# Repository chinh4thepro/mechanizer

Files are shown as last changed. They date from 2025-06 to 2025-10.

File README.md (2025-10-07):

tag

## What and Why?

This is an ortholinear, split keyboard with wireless functionality and a display with a theme based on the song Mesmerizer by 32ki. I designed this keyboard to improve on issues I had with my previous ortholinear keyboard design, the blahajergo.

## Images

### Overall
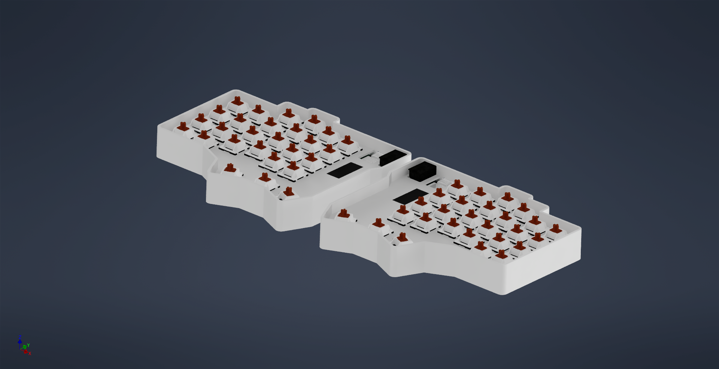
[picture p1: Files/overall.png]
Overall


### Schematic
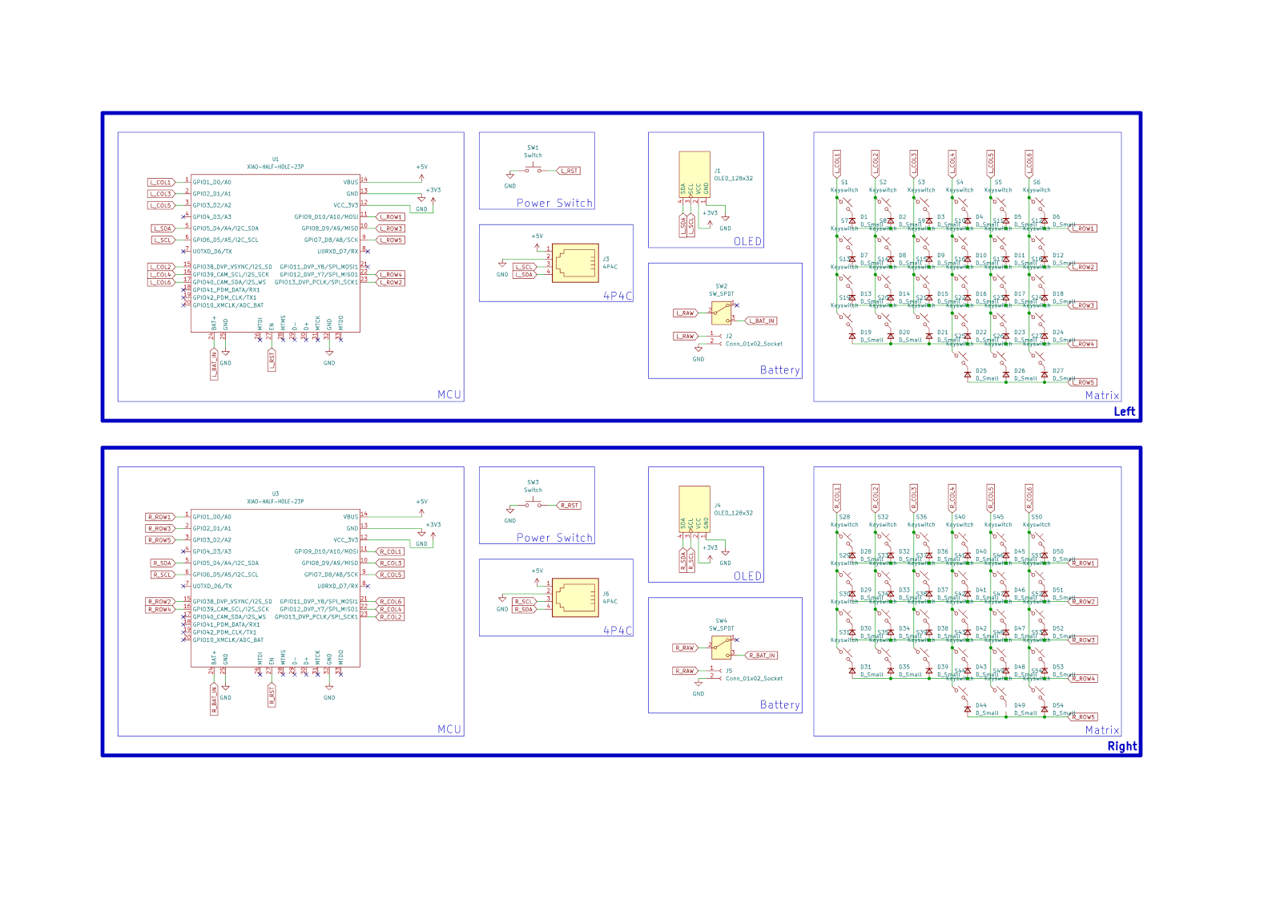
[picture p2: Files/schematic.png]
Schematic


### PCB
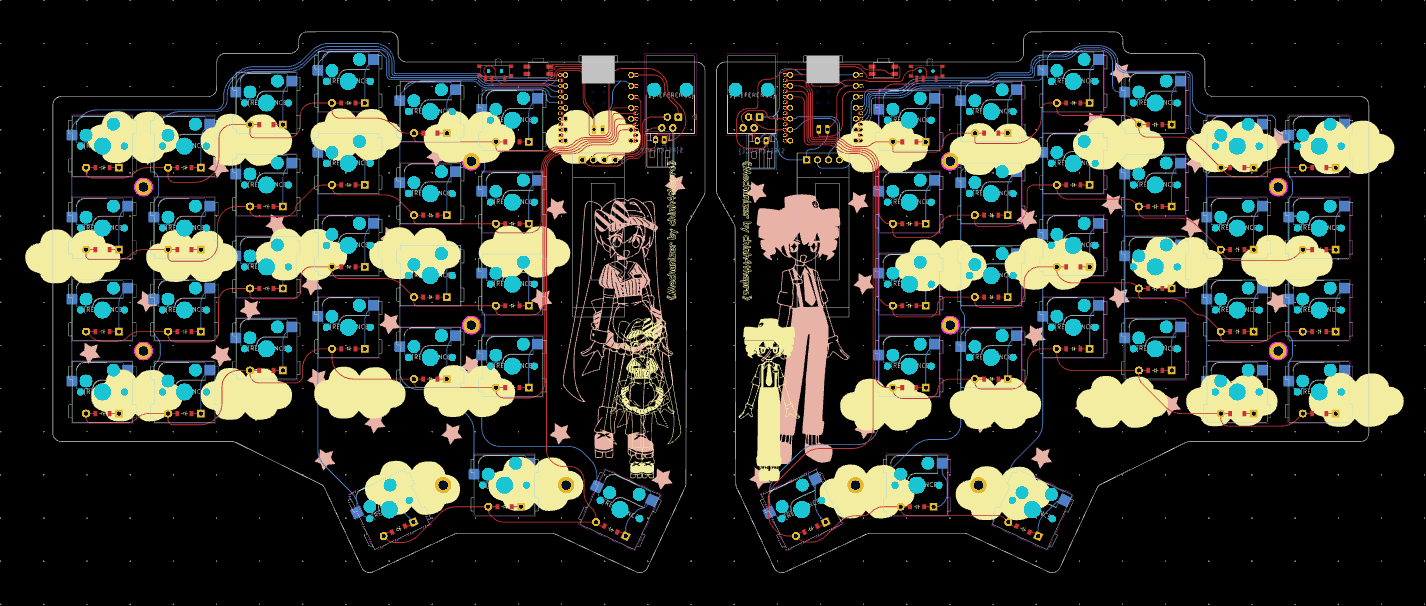
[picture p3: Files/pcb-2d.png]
PCB-2d

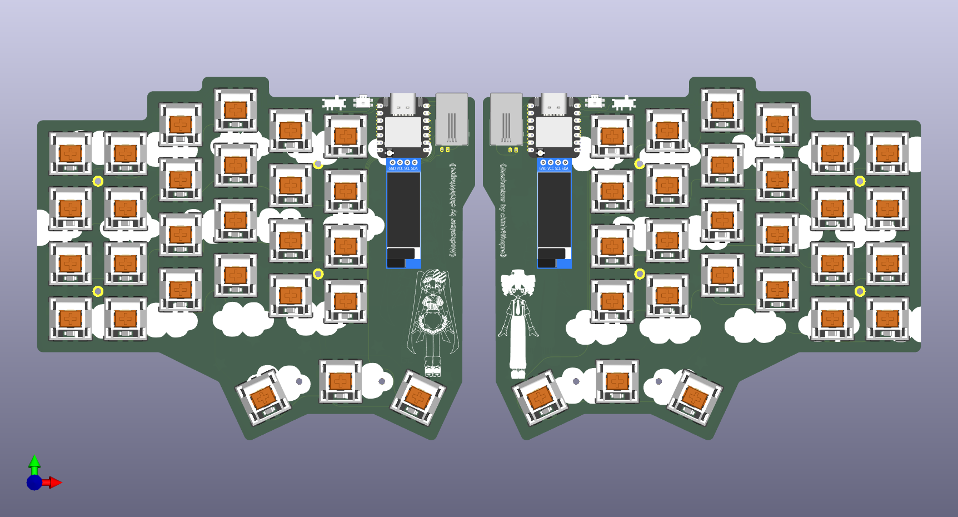
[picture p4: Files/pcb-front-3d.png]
PCB-3d-f

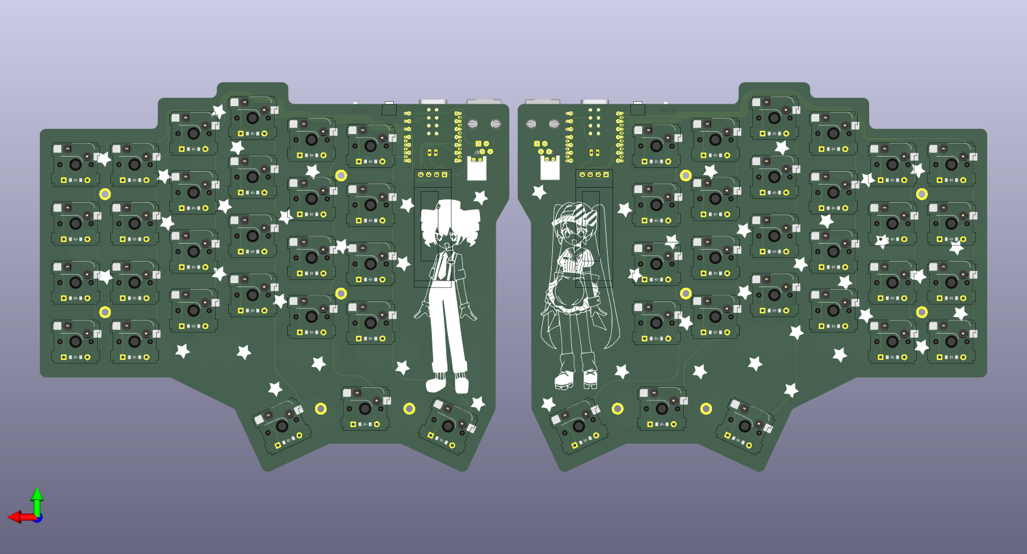
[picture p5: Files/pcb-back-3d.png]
PCB-3d-b


## BOM

| Name | Qty | Price | Vendor | Link |
|---|---|---|---|---|
| THT 1N4148 Diodes | 54 | $0.00 | HackClub | N/A |
| KBDiy Toy | 54 | $24.45 | AliExpress | https://www.aliexpress.us/item/3256807300360436.html |
| JWK Linear Switches | 54 | $14.4 | typeractive | https://typeractive.xyz/products/jwk-jwick-linear-switches?variant=45434593968359 |
| Kalih MX hotswap sockets | 54 | $13.45 | AliExpress | https://www.aliexpress.us/item/3256808768257055.html |
| 4P4C jack | 2 | $1.87 | AliExpress | https://www.aliexpress.us/item/3256807699240291.html |
| JST connector | 2 | $0.73 | AliExpress | https://www.aliexpress.us/item/3256808844534562.html |
| 0.91" Oled display | 2 | $1.96 | AliExpress | https://www.aliexpress.us/item/3256805114690528.html |
| 3.7v Lithium battery | 2 | $8.00 | typeractive | https://typeractive.xyz/products/lithium-battery-110mah?variant=43294731665639 |
| JST connector | 2 | $1.00 | typeractive | https://typeractive.xyz/products/battery-jack?variant=45597492707559 |
| SMD side button | 2 | $1.50 | typeractive | https://typeractive.xyz/products/reset-button |
| SPDT Switch | 2 | $1.50 | typeractive | https://typeractive.xyz/products/power-switch?variant=45597854171367 |
| M2 screws | 24 | $2.44 | AliExpress | https://www.aliexpress.us/item/2255799870438450.html |
| M2 standoffs | 12 | $5.40 | AliExpress | https://www.aliexpress.us/item/3256806016664762.html |
| Seeed XIAO ESP32-S3 Plus (already own) | 2 | $13.80 | seeedstudio | https://www.seeedstudio.com/Seeed-Studio-XIAO-ESP32S3-Plus-p-6361.html |
| PCB | 1 (5) | $36.92 | jlcpcb | See jlcpcb pic in Files |

| Total                                                                                                                                             |
|---------------------------------------------------------------------------------------------------------------------------------------------------|
| AliExpress: $52.83 subtotal + $4.24 shipping + $3.33 fees = $58.61 total                                                                          |
| typeractive: $26.40 subtotal + $0.00 shipping + $0.00 fees = $26.40 total                                                                         |
| seeedstudio: $0.00 subtotal + $0.00 shipping + $0.00 fees = $0.00 total                                                                           |
| jlcpcb: $21.40 subtotal + $15.52 shipping + $0.00 fees = $36.92 total                                                                             |
| Total: $121.93                                                                                                                                     |

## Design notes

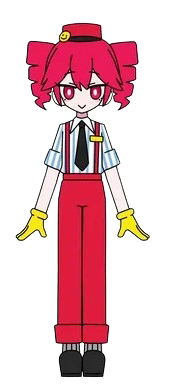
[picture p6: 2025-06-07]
Files/teto-1.png

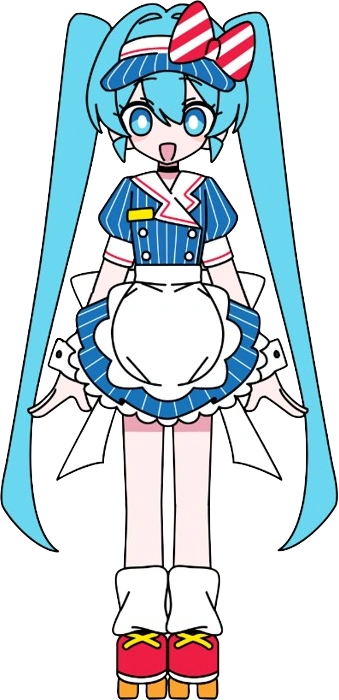
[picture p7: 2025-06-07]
Files/miku-1.png

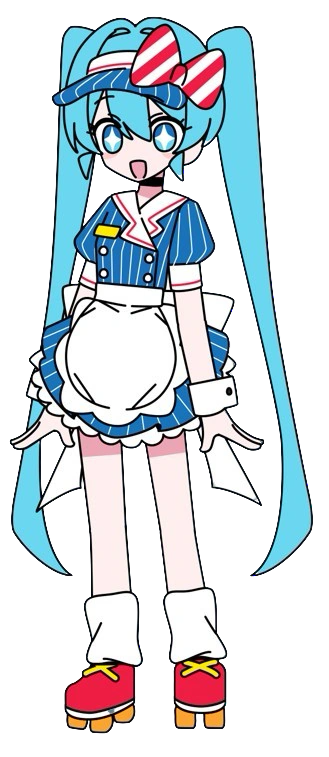
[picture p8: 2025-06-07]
Files/miku-2.png

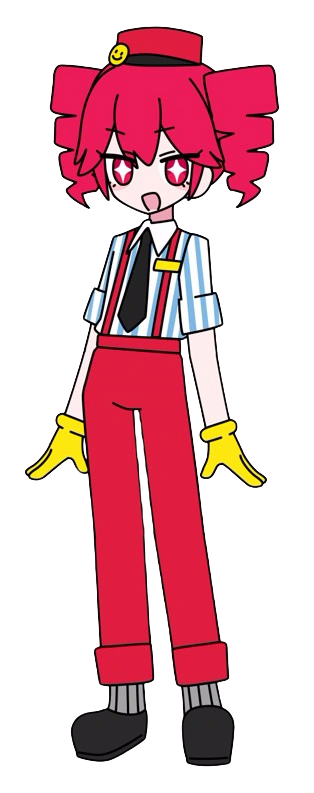
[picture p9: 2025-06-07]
Files/teto-2.png

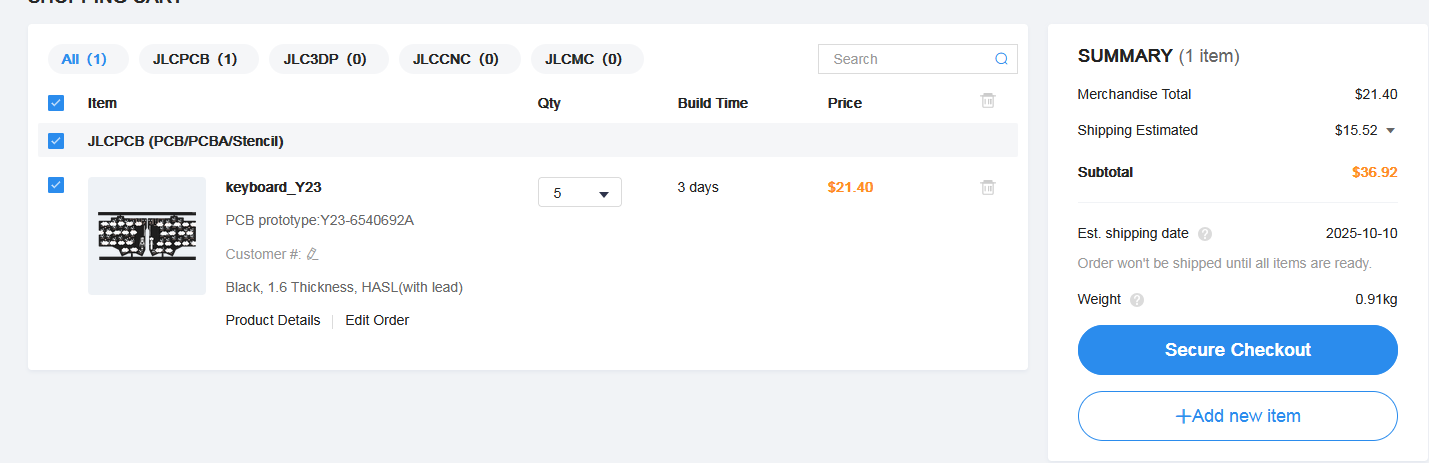
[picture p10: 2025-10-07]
Files/jlcpcb.png

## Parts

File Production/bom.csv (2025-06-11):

Designator | Footprint | Quantity | Value | LCSC Part #
D1, D10, D11, D12, D13, D14, D15, D16, D17, D18, D19, D2, D20, D21, D22, D23, D24, D25, D26, D27, D28, D29, D3, D30, D31, D32, D33, D34, D35, D36, D37, D38, D39, D4, D40, D41, D42, D43, D44, D45, D46, D47, D48, D49, D5, D50, D51, D52, D53, D54, D6, D7, D8, D9 | ComboDiode | 54 | D_Small
H1, H10, H11, H12, H2, H3, H4, H5, H6, H7, H8, H9 | mounting_hole_plated | 12
J1, J4 | OLED_128x32 | 2 | OLED_128x32
J2, J5 | JST_PH_S2B-PH-K_1x02_P2.00mm_Horizontal | 2 | Conn_01x02_Socket
J3, J6 | RJ9_Evercom_5301-440xxx_Horizontal | 2 | 4P4C
S1, S10, S11, S12, S13, S14, S15, S16, S17, S18, S19, S2, S20, S21, S22, S23, S24, S25, S26, S27, S28, S29, S3, S30, S31, S32, S33, S34, S35, S36, S37, S38, S39, S4, S40, S41, S42, S43, S44, S45, S46, S47, S48, S49, S5, S50, S51, S52, S53, S54, S6, S7, S8, S9 | Hotswap_MX | 54 | Keyswitch
SW1, SW3 | reset_switch_smd_side | 2 | Switch
SW2, SW4 | power_switch_smd_side | 2 | SW_SPDT
U1, U3 | Xiao_ESP32S3_Plus.kicad_sym | 2 | XIAO-HALF-HOLE-23P

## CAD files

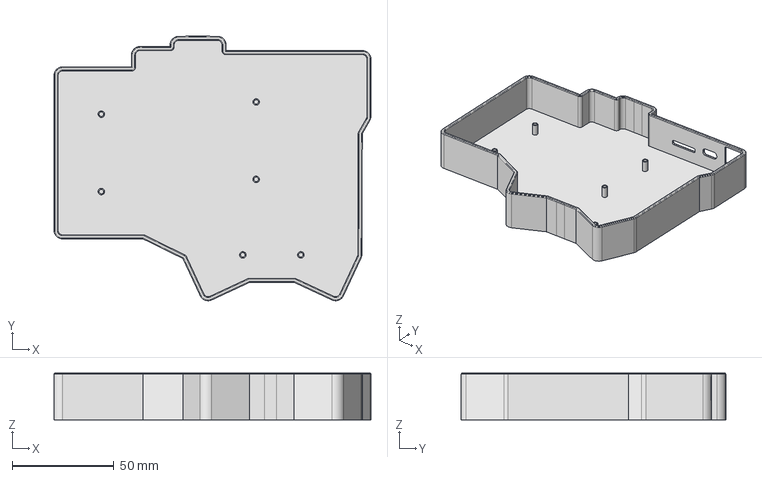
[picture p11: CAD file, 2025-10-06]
CAD/Exports/Left_Shell.step
155.6 x 129.9 x 23.0 mm

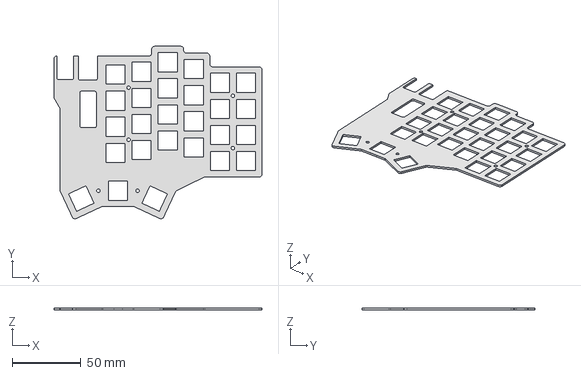
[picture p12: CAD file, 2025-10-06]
CAD/Exports/Right_Plate.step
151.4 x 125.7 x 1.50 mm

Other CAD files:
CAD/Exports/Right_Shell.step
CAD/Exports/Left_Plate.step
CAD/Exports/Left_Plate.3mf
CAD/Exports/Left_Shell.3mf
CAD/Exports/Right_Plate.3mf
CAD/Exports/Right_Shell.3mf

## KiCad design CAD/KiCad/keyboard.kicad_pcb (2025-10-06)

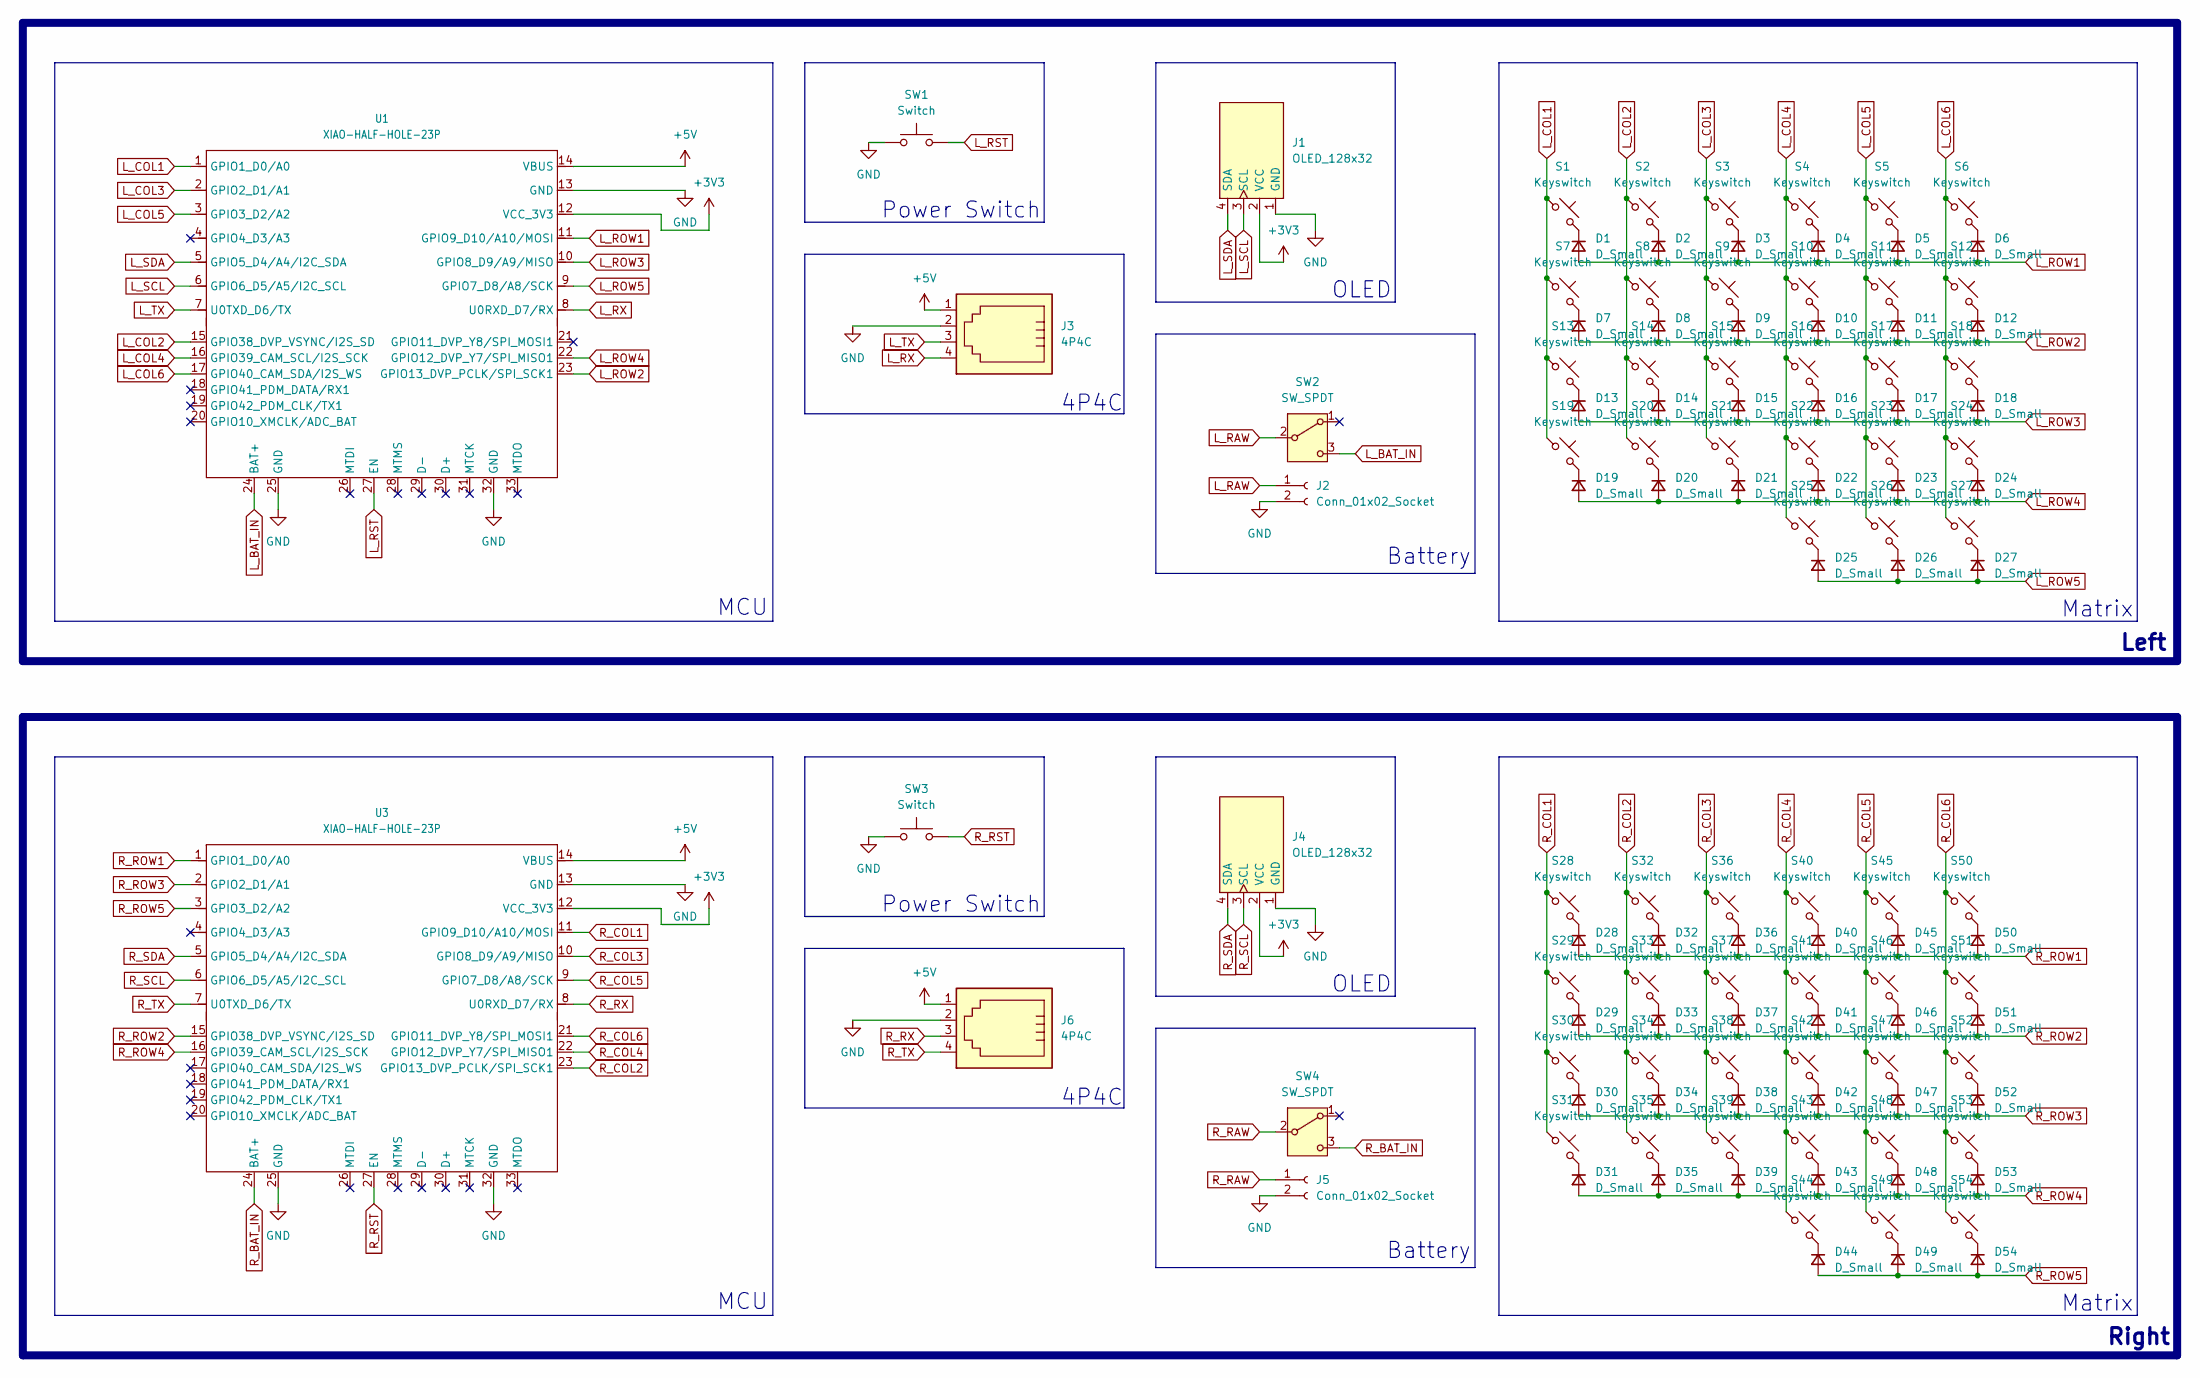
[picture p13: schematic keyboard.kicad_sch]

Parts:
D1, D2, D3, D4, D5, D6, D7, D8, D9, D10, D11, D12, D13, D14, D15, D16, D17, D18, D19, D20, D21, D22, D23, D24, D25, D26, D27, D28, D29, D30, D31, D32, D33, D34, D35, D36, D37, D38, D39, D40, D41, D42, D43, D44, D45, D46, D47, D48, D49, D50, D51, D52, D53, D54: D_Small; ComboDiode
J1, J4: OLED_128x32
J2, J5: Conn_01x02_Socket; JST_PH_S2B-PH-K_1x02_P2.00mm_Horizontal
J3, J6: 4P4C; RJ9_Evercom_5301-440xxx_Horizontal
S1, S2, S3, S4, S5, S6, S7, S8, S9, S10, S11, S12, S13, S14, S15, S16, S17, S18, S19, S20, S21, S22, S23, S24, S25, S26, S27, S28, S29, S30, S31, S32, S33, S34, S35, S36, S37, S38, S39, S40, S41, S42, S43, S44, S45, S46, S47, S48, S49, S50, S51, S52, S53, S54: Keyswitch; Hotswap_MX
SW1, SW3: Switch; reset_switch_smd_side
SW2, SW4: SW_SPDT; power_switch_smd_side
U1, U3: XIAO-HALF-HOLE-23P; Xiao_ESP32S3_Plus.kicad_sym

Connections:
+3V3: J1.2 (VCC), J4.2 (VCC), U1.12 (VCC_3V3), U3.12 (VCC_3V3)
+5V: J3.1, J6.1, U1.14 (VBUS), U3.14 (VBUS)
GND: J1.1 (GND), J2.2, J3.2, J4.1 (GND), J5.2, J6.2, SW1.1, SW3.1, U1.13 (GND), U1.25 (GND), U1.32 (GND), U3.13 (GND), U3.25 (GND), U3.32 (GND)
L_BAT_IN: SW2.3 (C), U1.24 (BAT+)
L_COL1: S1.1, S7.1, S13.1, S19.1, U1.1 (GPIO1_D0/A0)
L_COL2: S2.1, S8.1, S14.1, S20.1, U1.15 (GPIO38_DVP_VSYNC/I2S_SD)
L_COL3: S3.1, S9.1, S15.1, S21.1, U1.2 (GPIO2_D1/A1)
L_COL4: S4.1, S10.1, S16.1, S22.1, S25.1, U1.16 (GPIO39_CAM_SCL/I2S_SCK)
L_COL5: S5.1, S11.1, S17.1, S23.1, S26.1, U1.3 (GPIO3_D2/A2)
L_COL6: S6.1, S12.1, S18.1, S24.1, S27.1, U1.17 (GPIO40_CAM_SDA/I2S_WS)
L_RAW: J2.1, SW2.2 (B)
L_ROW1: D1.2 (A), D2.2 (A), D3.2 (A), D4.2 (A), D5.2 (A), D6.2 (A), U1.11 (GPIO9_D10/A10/MOSI)
L_ROW2: D7.2 (A), D8.2 (A), D9.2 (A), D10.2 (A), D11.2 (A), D12.2 (A), U1.23 (GPIO13_DVP_PCLK/SPI_SCK1)
L_ROW3: D13.2 (A), D14.2 (A), D15.2 (A), D16.2 (A), D17.2 (A), D18.2 (A), U1.10 (GPIO8_D9/A9/MISO)
L_ROW4: D19.2 (A), D20.2 (A), D21.2 (A), D22.2 (A), D23.2 (A), D24.2 (A), U1.22 (GPIO12_DVP_Y7/SPI_MISO1)
L_ROW5: D25.2 (A), D26.2 (A), D27.2 (A), U1.9 (GPIO7_D8/A8/SCK)
L_RST: SW1.2, U1.27 (EN)
L_RX: J3.4, U1.8 (U0RXD_D7/RX)
L_SCL: J1.3 (SCL), U1.6 (GPIO6_D5/A5/I2C_SCL)
L_SDA: J1.4 (SDA), U1.5 (GPIO5_D4/A4/I2C_SDA)
L_TX: J3.3, U1.7 (U0TXD_D6/TX)
unnamed: D1.1 (K), S1.2
unnamed: D2.1 (K), S2.2
unnamed: D3.1 (K), S3.2
unnamed: D4.1 (K), S4.2
unnamed: D5.1 (K), S5.2
unnamed: D6.1 (K), S6.2
unnamed: D7.1 (K), S7.2
unnamed: D8.1 (K), S8.2
unnamed: D9.1 (K), S9.2
unnamed: D10.1 (K), S10.2
unnamed: D11.1 (K), S11.2
unnamed: D12.1 (K), S12.2
unnamed: D13.1 (K), S13.2
unnamed: D14.1 (K), S14.2
unnamed: D15.1 (K), S15.2
unnamed: D16.1 (K), S16.2
unnamed: D17.1 (K), S17.2
unnamed: D18.1 (K), S18.2
unnamed: D19.1 (K), S19.2
unnamed: D20.1 (K), S20.2
unnamed: D21.1 (K), S21.2
unnamed: D22.1 (K), S22.2
unnamed: D23.1 (K), S23.2
unnamed: D24.1 (K), S24.2
unnamed: D25.1 (K), S25.2
unnamed: D26.1 (K), S26.2
unnamed: D27.1 (K), S27.2
unnamed: D28.1 (K), S28.2
unnamed: D29.1 (K), S29.2
unnamed: D30.1 (K), S30.2
unnamed: D31.1 (K), S31.2
unnamed: D32.1 (K), S32.2
unnamed: D33.1 (K), S33.2
unnamed: D34.1 (K), S34.2
unnamed: D35.1 (K), S35.2
unnamed: D36.1 (K), S36.2
unnamed: D37.1 (K), S37.2
unnamed: D38.1 (K), S38.2
unnamed: D39.1 (K), S39.2
unnamed: D40.1 (K), S40.2
unnamed: D41.1 (K), S41.2
unnamed: D42.1 (K), S42.2
unnamed: D43.1 (K), S43.2
unnamed: D44.1 (K), S44.2
unnamed: D45.1 (K), S45.2
unnamed: D46.1 (K), S46.2
unnamed: D47.1 (K), S47.2
unnamed: D48.1 (K), S48.2
unnamed: D49.1 (K), S49.2
unnamed: D50.1 (K), S50.2
unnamed: D51.1 (K), S51.2
unnamed: D52.1 (K), S52.2
unnamed: D53.1 (K), S53.2
unnamed: D54.1 (K), S54.2
R_BAT_IN: SW4.3 (C), U3.24 (BAT+)
R_COL1: S28.1, S29.1, S30.1, S31.1, U3.11 (GPIO9_D10/A10/MOSI)
R_COL2: S32.1, S33.1, S34.1, S35.1, U3.23 (GPIO13_DVP_PCLK/SPI_SCK1)
R_COL3: S36.1, S37.1, S38.1, S39.1, U3.10 (GPIO8_D9/A9/MISO)
R_COL4: S40.1, S41.1, S42.1, S43.1, S44.1, U3.22 (GPIO12_DVP_Y7/SPI_MISO1)
R_COL5: S45.1, S46.1, S47.1, S48.1, S49.1, U3.9 (GPIO7_D8/A8/SCK)
R_COL6: S50.1, S51.1, S52.1, S53.1, S54.1, U3.21 (GPIO11_DVP_Y8/SPI_MOSI1)
R_RAW: J5.1, SW4.2 (B)
R_ROW1: D28.2 (A), D32.2 (A), D36.2 (A), D40.2 (A), D45.2 (A), D50.2 (A), U3.1 (GPIO1_D0/A0)
R_ROW2: D29.2 (A), D33.2 (A), D37.2 (A), D41.2 (A), D46.2 (A), D51.2 (A), U3.15 (GPIO38_DVP_VSYNC/I2S_SD)
R_ROW3: D30.2 (A), D34.2 (A), D38.2 (A), D42.2 (A), D47.2 (A), D52.2 (A), U3.2 (GPIO2_D1/A1)
R_ROW4: D31.2 (A), D35.2 (A), D39.2 (A), D43.2 (A), D48.2 (A), D53.2 (A), U3.16 (GPIO39_CAM_SCL/I2S_SCK)
R_ROW5: D44.2 (A), D49.2 (A), D54.2 (A), U3.3 (GPIO3_D2/A2)
R_RST: SW3.2, U3.27 (EN)
R_RX: J6.3, U3.8 (U0RXD_D7/RX)
R_SCL: J4.3 (SCL), U3.6 (GPIO6_D5/A5/I2C_SCL)
R_SDA: J4.4 (SDA), U3.5 (GPIO5_D4/A4/I2C_SDA)
R_TX: J6.4, U3.7 (U0TXD_D6/TX)

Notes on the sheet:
Power Switch
Left
Battery
Matrix
4P4C
Right
MCU
OLED

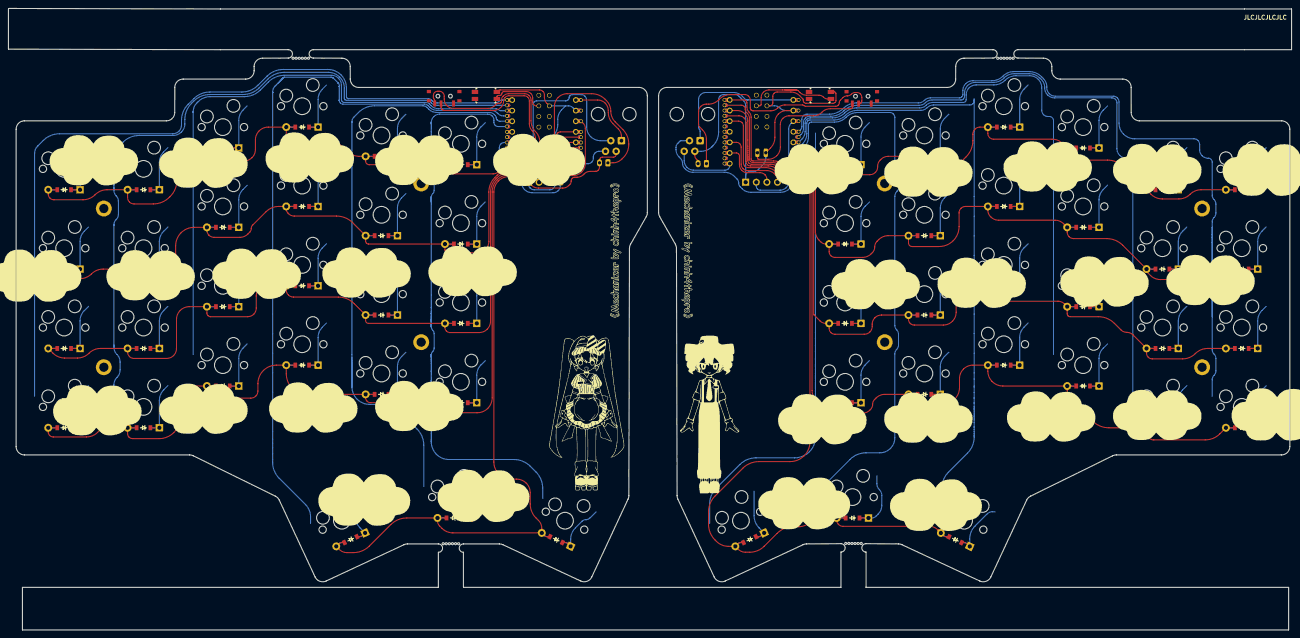
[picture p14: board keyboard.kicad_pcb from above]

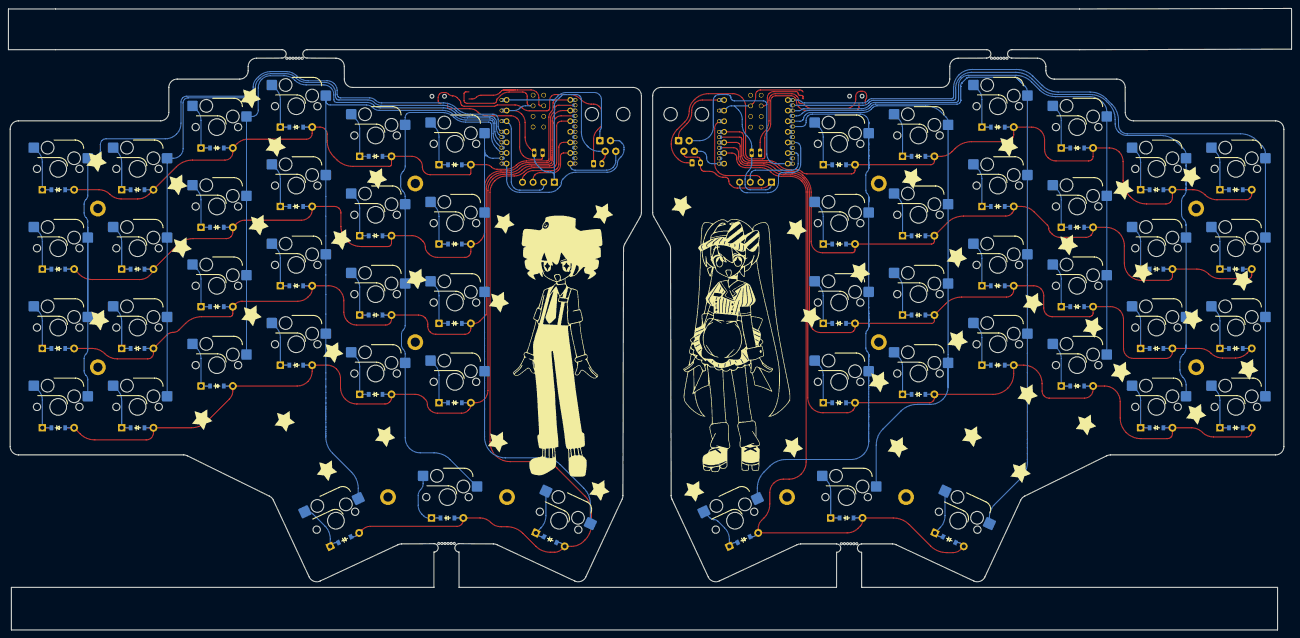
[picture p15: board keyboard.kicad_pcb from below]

Board: 2 copper layers, 307.2 x 148.8 mm, 132 parts (2 on the bottom side), 93 nets.

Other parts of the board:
H1, H2, H3, H4, H5, H6, H7, H8, H9, H10, H11, H12: mounting_hole_plated

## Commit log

2025-06-07 partially update pt2
    [keyboard.kicad_pcb, keyboard.kicad_sch]
2025-06-07 complete images
    [keyboard.kicad_pcb]
2025-06-07 update images
    [keyboard.kicad_pcb]
2025-06-07 redo mousebites cause i forgor
    [keyboard.kicad_pcb]
2025-06-09 cad files
    [Left_Plate.3mf, Left_Shell.3mf, Right_Plate.3mf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]
2025-06-11 reroute for full duplex split functionality
    [bom.csv, designators.csv, keyboard.kicad_pcb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]
2025-06-11 bom in csv format
    [BOM.csv]
2025-06-11 update BOM
    [BOM.csv]
2025-10-06 i forgor the step files
    [Left_Plate.step, Left_Shell.step, Right_Plate.step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]
2025-10-07 add pcb to bom
    [BOM.csv]
2025-10-09 move production directory
    [bom.csv, designators.csv, positions.csv]
